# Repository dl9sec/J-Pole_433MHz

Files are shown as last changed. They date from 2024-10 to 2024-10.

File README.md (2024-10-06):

# Construction of a weather proof J Pole antenna for 433..434 MHz
This is a contruction of a weather proof J Pole antenna which can be used as a stationary antenna e.g. for [MeshCom](https://icssw.org/meshcom). The antenna is tuned to 433.5MHz resonance frequency and has a return loss better than ~20dB within +/-2MHz. 

The basic calculations for the antenna were made with [John Parfrey's (M0UKD) excellent J Pole/Slim Jim online calculator](https://m0ukd.com/calculators/slim-jim-and-j-pole-calculator). The velocity factor vf for the used material is about 0.95. The plastic parts and the covering tube are reducing the resonance frequency by about 10MHz (so the calculation frequency must be set to 443.5MHz).

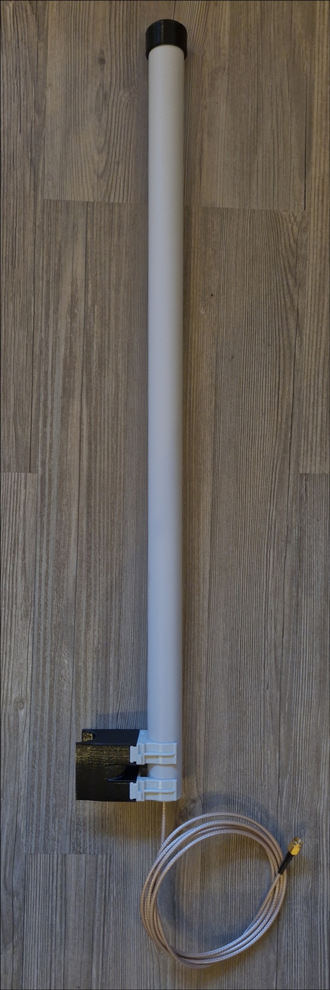
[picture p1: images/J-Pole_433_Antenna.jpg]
J Pole antenna

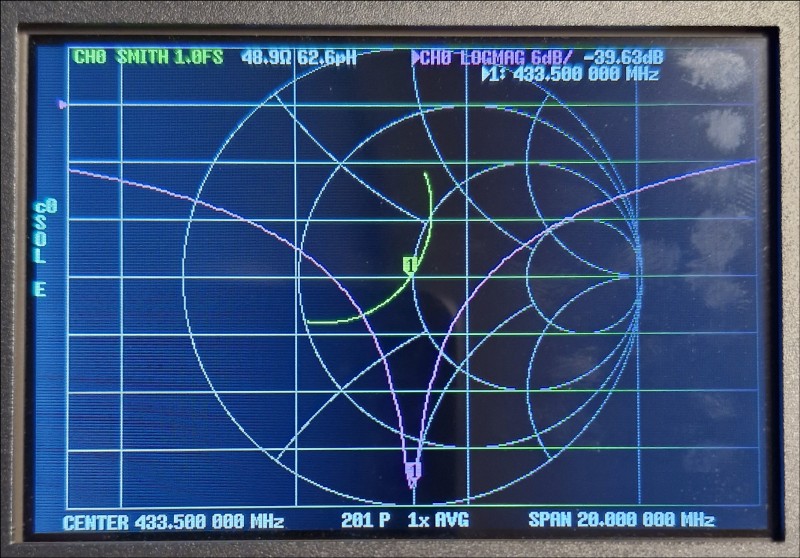
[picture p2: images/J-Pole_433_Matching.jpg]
J Pole antenna


# Material

## General parts
* Brass tube 6 mm diameter
* Brass tube 4 mm diameter
* Electric installation PVC tube 25 mm diameter
* Clamps for installation PVC tube 25 mm (optional, depends on mounting)
* 2x M5 x 9.5 x 7.1 threaded heat set inserts (optional, depends on mounting)
* 2x M2,5 x 6 countersunk screw (stainless steel if possible)
* 1x M3 x 10 Nylon
* 1x DIN912 M3 x 8 (stainless steel if possible)
* Clip-on ferrite about 13 mm diameter, about 26 mm length
* A piece of RG/RD-316 with a SMA connector (isolation parts are made of PTFE, so no problems at soldering the feedpoint)

## 3D printed parts
* J-Pole_433_Base, J-Pole_433_Bot1/2, J-Pole_433_Spacer and J-Pole_433_Top are made of PETG with 15% infill. J-Pole_433_Clamp is made of PETG with 50% infill. 2.1/2.4 mm holes are threaded with a thread cutter for M2.5 respectively M3.
* J-Pole_433_Cap is made of Shore 95A TPU (Eryone) with 100% infill.

All CAD files (FCStd format) can be found in the subdirectory "FreeCAD-Data". STL files for individual slicing can be found in the subdirectory "STL-Data". Ready-to-print BGCODE for Prusa MK4 printers can be found in the subdirectory "Prusa3D-Data".

# Contruction
Details about measures and assembly of the antenna can be found in [J-Pole_433MHz_DL9SEC.pdf](https://github.com/dl9sec/J-Pole_433MHz/blob/main/J-Pole_433MHz_DL9SEC.pdf).

1. The 6mm brass tube is cutted to the respective length. At one end a 4mm hole must be drilled (see drawing).
2. The 4mm brass tube should be simply bent carefully and then cutted to the given length.

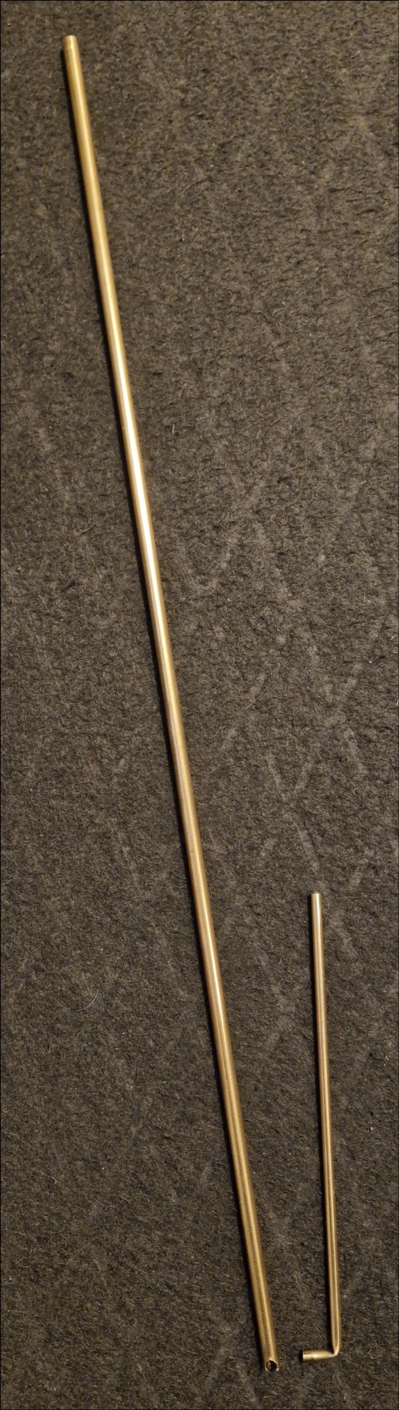
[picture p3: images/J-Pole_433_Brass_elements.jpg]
J Pole antenna

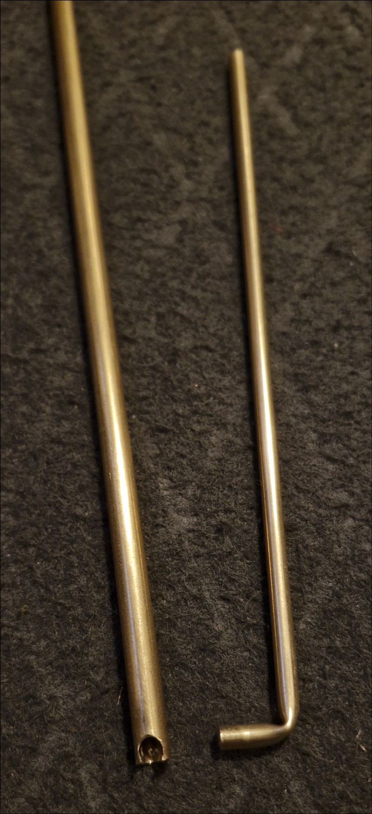
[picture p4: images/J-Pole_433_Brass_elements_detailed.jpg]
J Pole antenna


3. The 4mm tube is sticked into the drilled hole (see drawing) and brazed with brasing alloy (e.g. silver alloy, 650°C melting point).

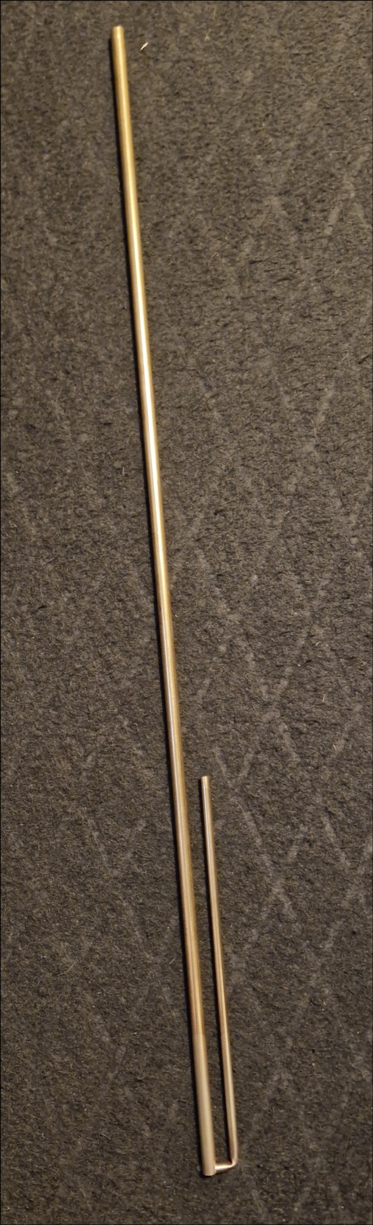
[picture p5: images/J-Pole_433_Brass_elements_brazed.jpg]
J Pole antenna

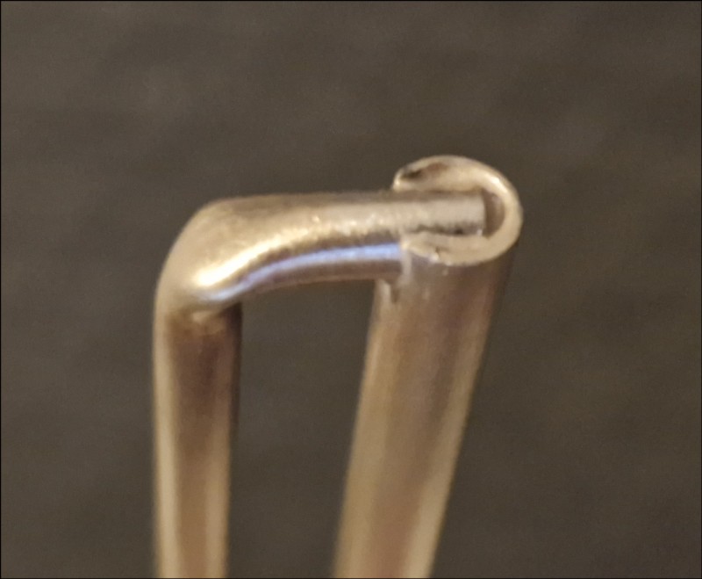
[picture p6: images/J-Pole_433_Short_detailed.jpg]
J Pole antenna


4. The spacer ("J-Pole_433_Spacer") is put on the tubes to stabilize the J.
5. The coaxial cable is soldered to the feedpoint (see drawing). Take care, that if the 6mm tube is on the left, the cable must be on the top side!

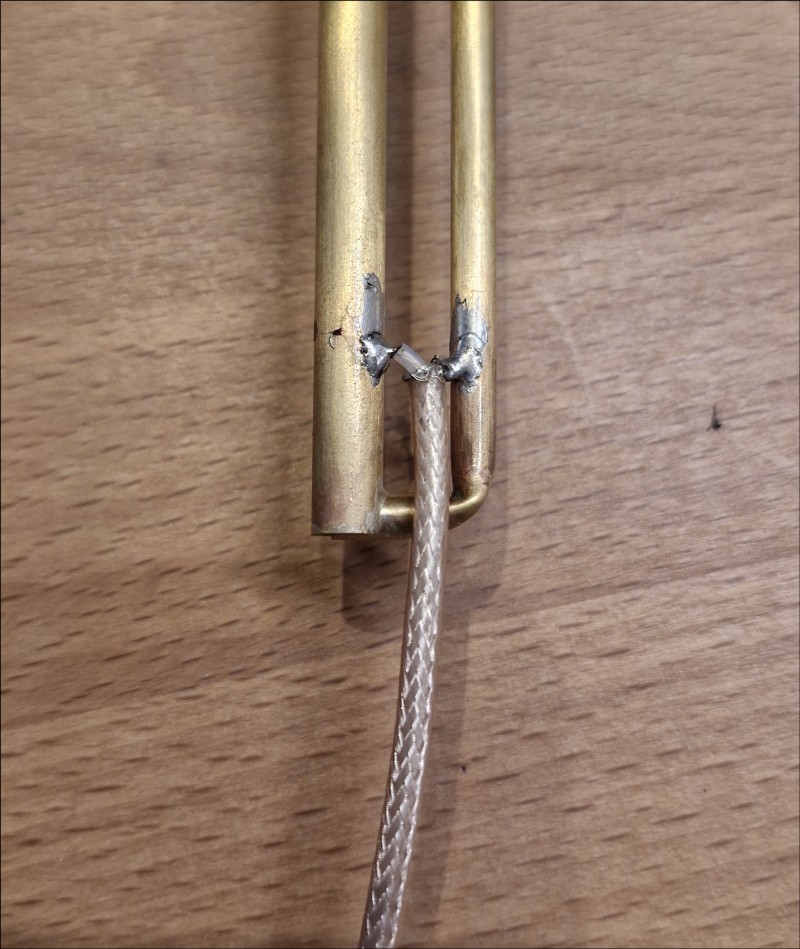
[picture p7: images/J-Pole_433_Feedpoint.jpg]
J Pole antenna


6. The shells "J-Pole_433_Bot1/2" are put arond the bottom of the antenna. The upper screw is the nylon one, the lower screw is the metal one.
7. Put the ferrite choke around the coax cable, then put "J-Pole_433_Base" around the cable and push both towards the antenna bottom.

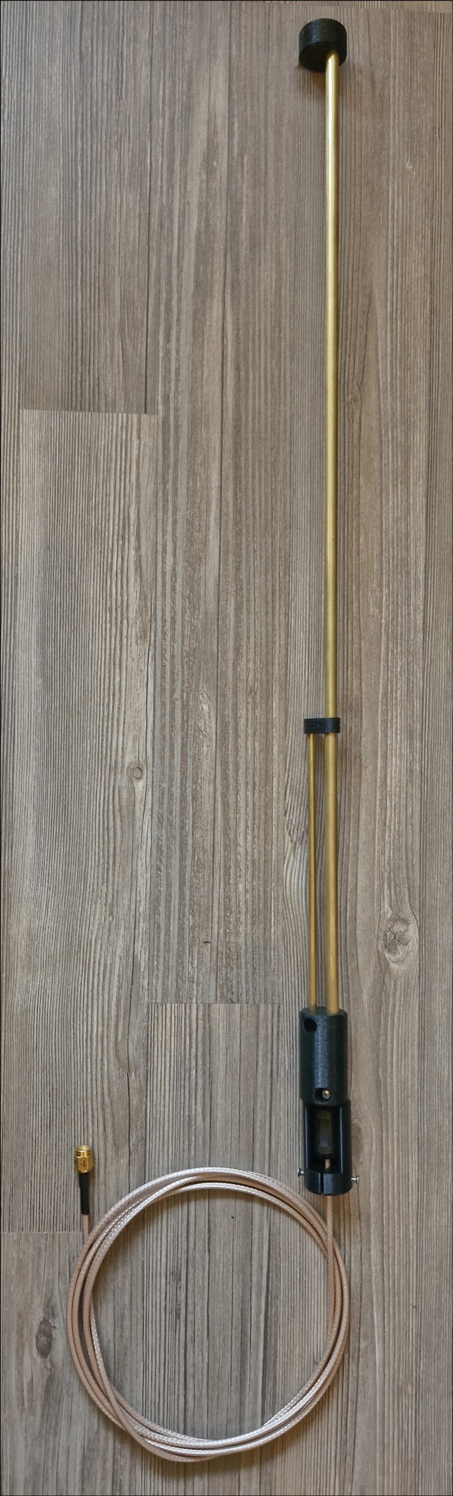
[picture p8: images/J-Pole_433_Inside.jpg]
J Pole antenna


8. Put all together into the PVC tube (it may be better to insert the "J-Pole_433_Top" after the antenna has been pushed into the tube).
9. Attach the antenna with the two screws at the bottom of the tube.
10. Put "J-Pole_433_Cap" on the top of the tube.

# Miscellaneous

The pole clamp adapter "J-Pole_433_Clamp" is optional. Two tube clamps can be attached by inserting two threaded heat set inserts. The adapter can be attached to a 25mm pole (e.g. at a weather station).

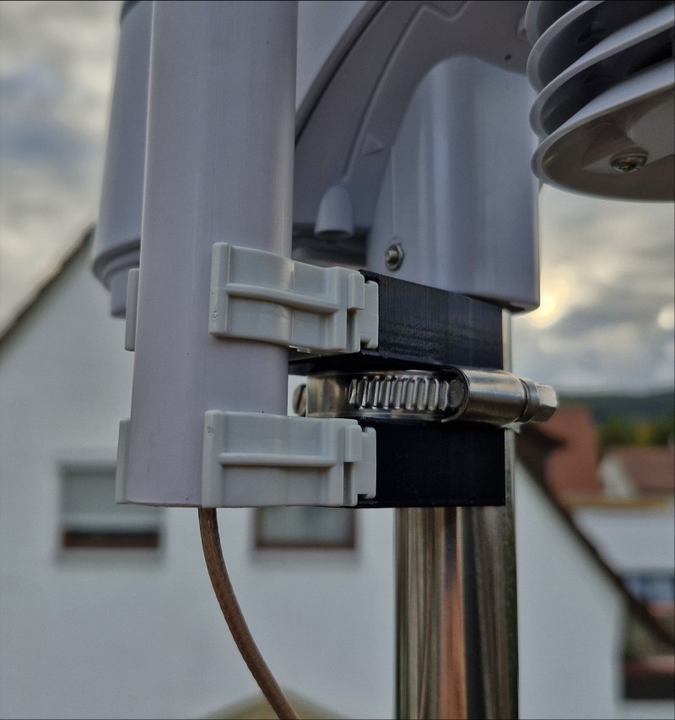
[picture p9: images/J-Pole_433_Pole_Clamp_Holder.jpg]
J Pole antenna


The parts are modeled with [FreeCAD](https://www.freecadweb.org/).

Copyright (C) 2024 by Thorsten Godau (DL9SEC). All stuff here is licensed under [Creative Commons Attribution-ShareAlike 4.0 International](https://creativecommons.org/licenses/by-sa/4.0).

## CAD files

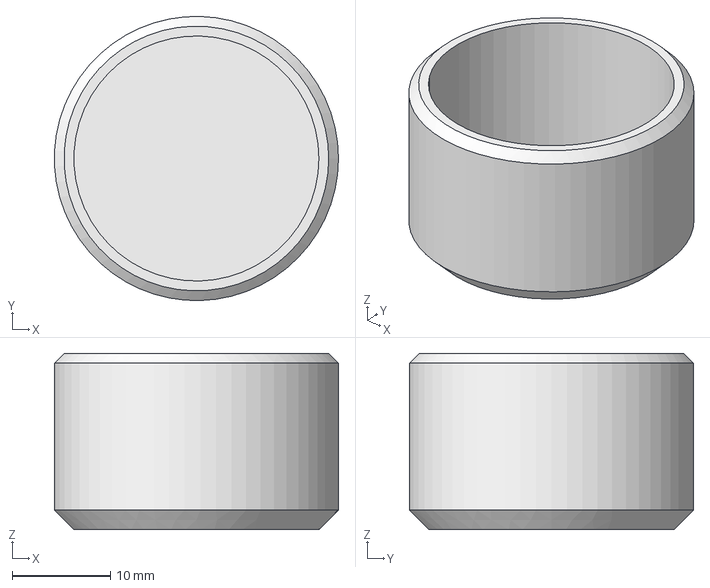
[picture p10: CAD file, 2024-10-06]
FreeCAD-Data/J-Pole_433_Cap.FCStd
29.0 x 29.0 x 18.0 mm

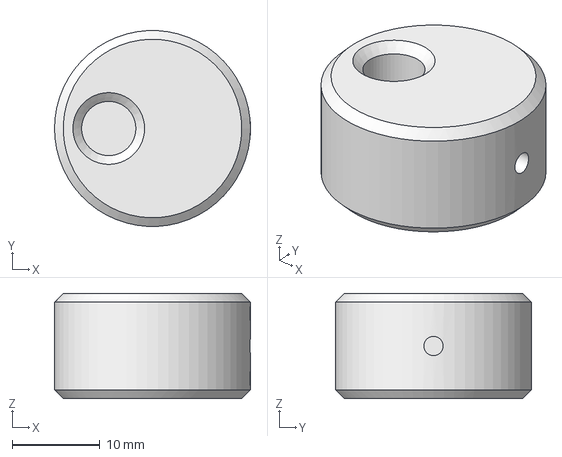
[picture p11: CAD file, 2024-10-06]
FreeCAD-Data/J-Pole_433_Top.FCStd
22.4 x 22.4 x 12.0 mm

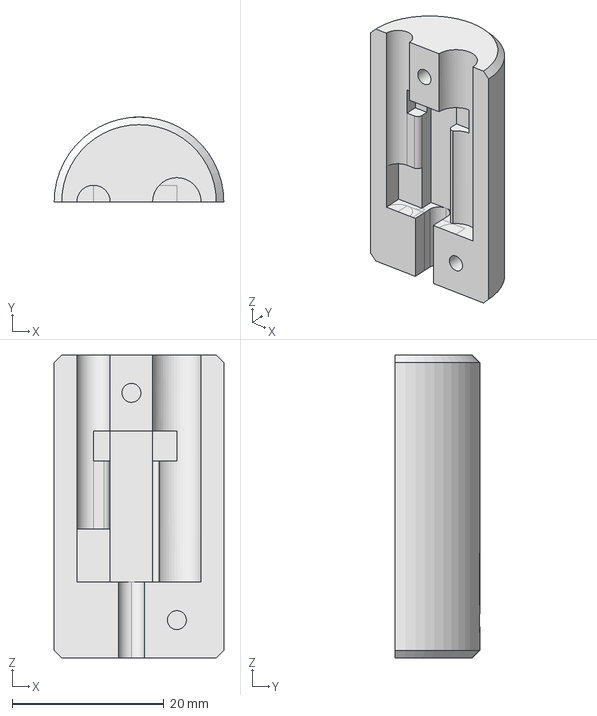
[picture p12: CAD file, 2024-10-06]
FreeCAD-Data/J-Pole_433_Bot2.FCStd
22.4 x 11.2 x 40.0 mm

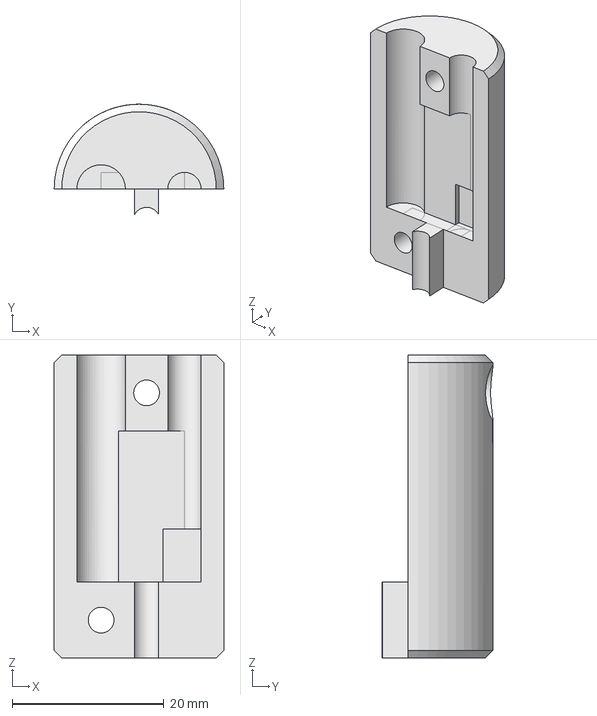
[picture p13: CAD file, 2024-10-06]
FreeCAD-Data/J-Pole_433_Bot1.FCStd
22.4 x 14.6 x 40.0 mm

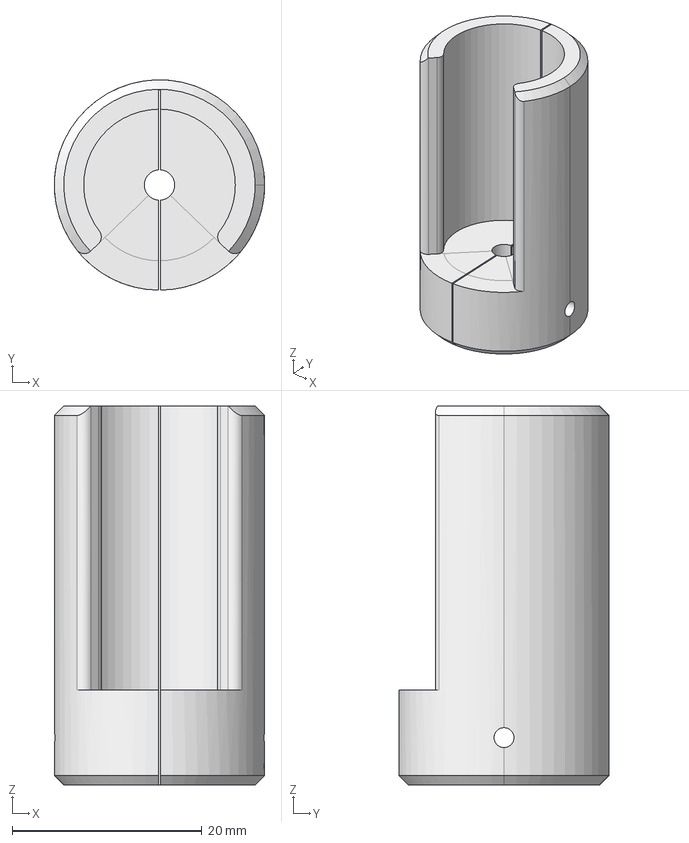
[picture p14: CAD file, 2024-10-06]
FreeCAD-Data/J-Pole_433_Base.FCStd
22.2 x 22.2 x 40.0 mm

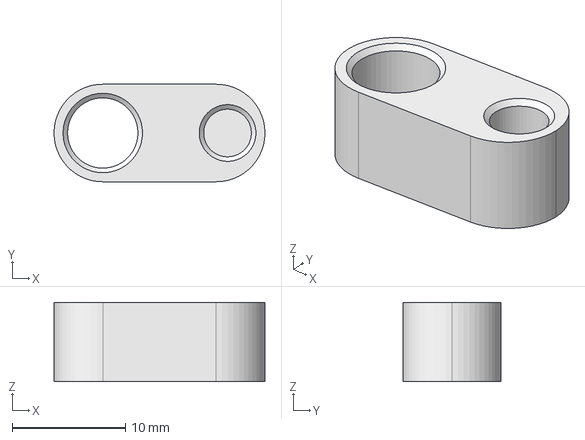
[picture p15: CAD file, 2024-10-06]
FreeCAD-Data/J-Pole_433_Spacer.FCStd
18.6 x 8.60 x 7.00 mm

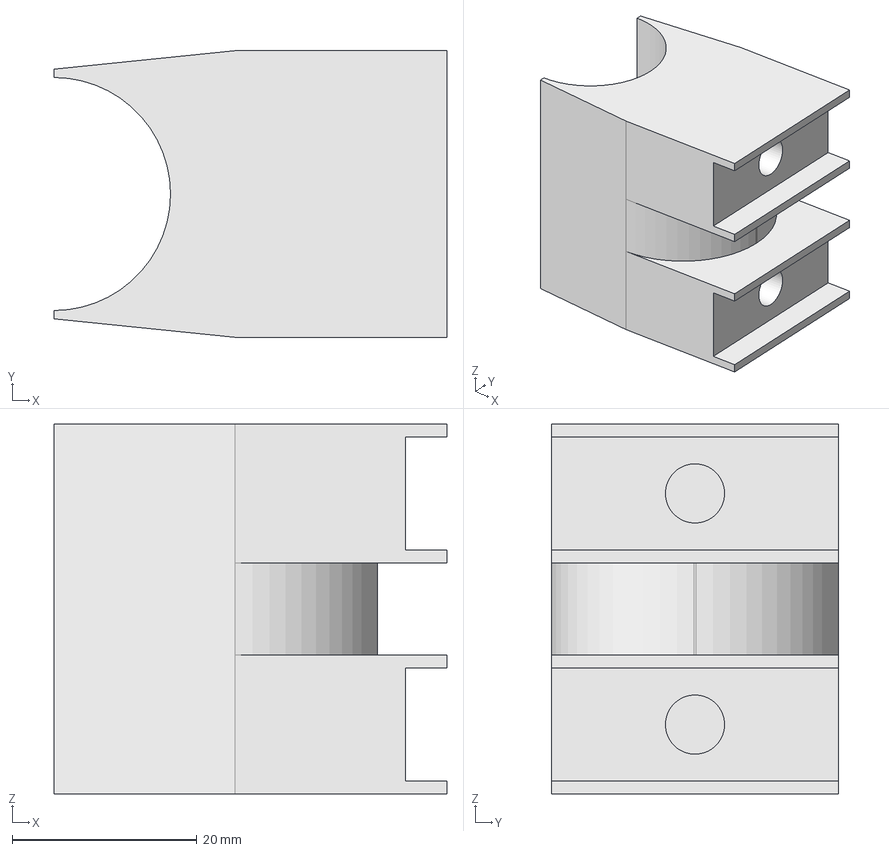
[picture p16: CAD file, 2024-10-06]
FreeCAD-Data/J-Pole_433_Clamp.FCStd
42.5 x 31.0 x 40.0 mm

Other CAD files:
STL-Data/J-Pole_433_Base.stl
STL-Data/J-Pole_433_Bot1.stl
STL-Data/J-Pole_433_Bot2.stl
STL-Data/J-Pole_433_Cap.stl
STL-Data/J-Pole_433_Clamp.stl
STL-Data/J-Pole_433_Spacer.stl
STL-Data/J-Pole_433_Top.stl

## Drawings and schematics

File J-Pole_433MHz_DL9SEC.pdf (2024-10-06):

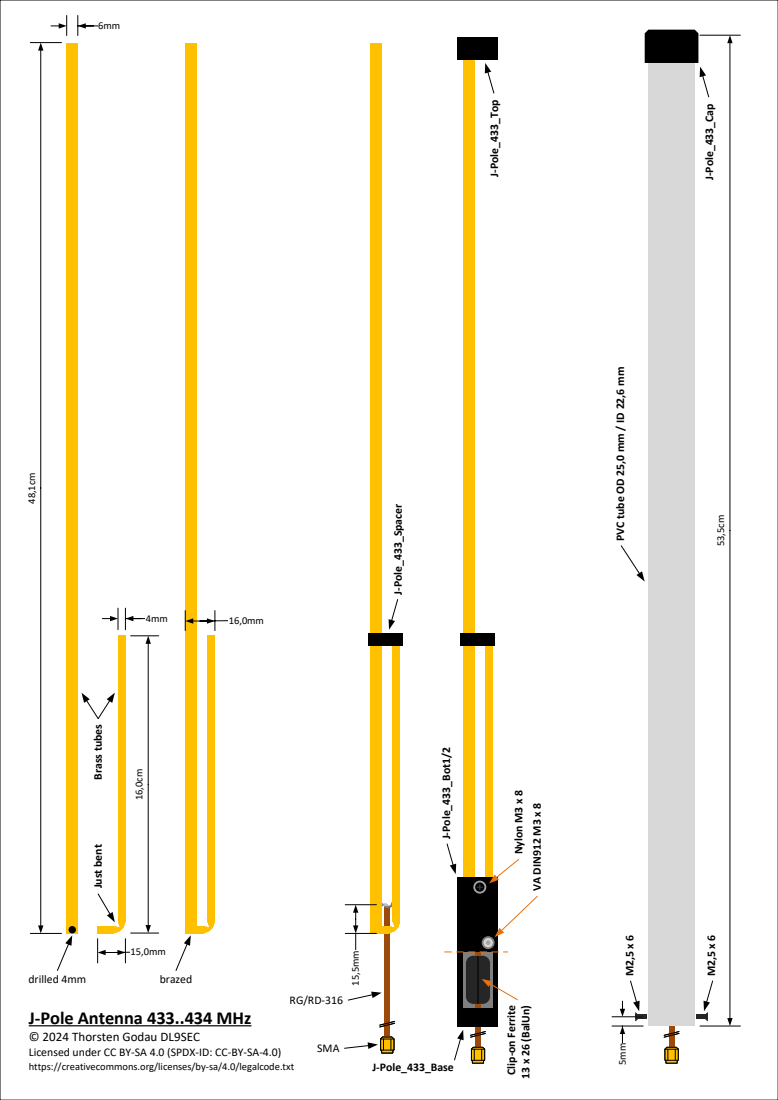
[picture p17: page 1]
drilled 4mm; brazed; J-Pole_433_Spacer; J-Pole_433_Top; J-Pole_433_Base; J-Pole_433_Bot1/2; J-Pole_433_Cap; SMA; Nylon M3 x 8; VA DIN912 M3 x 8; 13 x 26 (BalUn)

PVC tube OD 25,0 mm / ID 22,6 mm M2,5 x 6

Brass tubes Just bent

Clip-on Ferrite

J-Pole Antenna 433..434 MHz
© 2024 Thorsten Godau DL9SEC
Licensed under CC BY-SA 4.0 (SPDX-ID: CC-BY-SA-4.0)
https://creativecommons.org/licenses/by-sa/4.0/legalcode.txt

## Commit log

2024-10-06 Add files via upload
    Initial upload
    [J-Pole_433_Base.FCStd, J-Pole_433_Base.stl, J-Pole_433_Bot1.FCStd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]
2024-10-06 Update README.md
    Some corrections. Insert clamp image.
